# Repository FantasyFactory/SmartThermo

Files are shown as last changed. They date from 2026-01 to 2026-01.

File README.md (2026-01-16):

# SmartThermo
Smart advanced IR thermometer con ESP32-C3 e MicroPython

## Descrizione
Termometro a infrarossi "smart" basato su ESP32-C3 con display OLED SSD1306 e sensore MLX90614. Il progetto include un'interfaccia di configurazione navigabile tramite pulsanti e supporto per funzionalità avanzate come controllo WiFi, termostato PID e integrazione Tapo.

## Hardware

### Componenti
- **ESP32-C3**: microcontrollore con MicroPython
- **Display OLED SSD1306**: 128x64 pixel, interfaccia I2C
- **Sensore MLX90614**: termometro a infrarossi, interfaccia I2C
- **5 Pulsanti**: navigazione menu (UP, DOWN, LEFT, RIGHT, FIRE)
- **Laser**: puntatore per misurazione
- **Buzzer**: feedback audio

### Pinout
```
PIN_SDA    = 5   # I2C Data
PIN_SCL    = 6   # I2C Clock
PIN_LEFT   = 3   # Pulsante sinistra
PIN_RIGHT  = 4   # Pulsante destra
PIN_FIRE   = 0   # Pulsante fuoco/conferma
PIN_LASER  = 9   # Controllo laser
PIN_UP     = 10  # Pulsante su
PIN_DOWN   = 7   # Pulsante giù
PIN_BUZZER = 1   # Buzzer
```

### Connessioni I2C
- Frequenza I2C: 100kHz (limitata dal sensore MLX90614)
- Display OLED: indirizzo 0x3C
- Sensore MLX90614: indirizzo 0x5A (default)

## Struttura Software

Il progetto è organizzato in modo modulare per ottimizzare l'uso della memoria di MicroPython:

```
src/
├── boot.py              # Script di avvio automatico
├── main.py              # Entry point principale
├── config.py            # Gestione configurazione (singleton)
├── config.json          # File di configurazione
├── menu.py              # Sistema di menu generico
├── setup.py             # App di configurazione
├── app.py               # App principale termometro
├── wifi_manager.py      # Gestione WiFi (STA/AP/BOTH)
├── web_server.py        # Web server HTTP con API REST
├── drivers/
│   ├── ssd1306.py       # Driver display OLED
│   └── mlx90614.py      # Driver sensore temperatura IR
└── static/
    ├── index.html       # Interfaccia web
    ├── style.css        # Stili interfaccia
    └── app.js           # JavaScript interfaccia
```

### Architettura

#### 1. Config (`config.py`)
Classe singleton per gestire la configurazione:
- Lettura/scrittura file JSON
- Accesso tramite properties (es. `config.PIN_UP`, `config.wifi_mode`)
- Metodi `get(path)` e `set(path, value)` per accesso gerarchico
- Metodo `reload()` per ricaricare dopo modifiche

#### 2. Menu (`menu.py`)
Sistema di menu navigabile generico che supporta:
- **Label**: separatori/etichette
- **Level**: menu con sottovoci
- **Action**: esegue un callback
- **Int**: valori interi con min/max/step
- **Float**: valori decimali con min/max/step
- **IP**: indirizzi IPv4 (4 ottetti 0-255)
- **List**: selezione da lista di stringhe
- **Bool**: ON/OFF

Navigazione:
- **UP/DOWN**: scorrono le voci (o modificano valori in editing)
- **RIGHT**: entra in sottomenu/editing o esegue azione
- **LEFT**: esce da sottomenu/editing

#### 3. Setup (`setup.py`)
App di configurazione che mappa i valori di `config.json` su un menu navigabile:
- WiFi: Mode, SSID selection
- Preferences: Laser, BigNum, Reading mode, Refresh rate
- Thermostat: Active, Target, PID parameters, Auto-tune
- Tapo: Enable, IP
- Save and Exit / Exit (without save)

#### 4. Main (`main.py`)
Entry point che:
- Inizializza hardware (I2C, display, sensori)
- Controlla se entrare in setup mode (pulsante FIRE premuto all'avvio)
- Gestisce il passaggio tra app con cleanup memoria
- Avvia l'app principale

## Configurazione

Il file `config.json` contiene tutte le impostazioni:

```json
{
  "pins": { ... },
  "wifi": {
    "mode": "AP|STA|BOTH|Off",
    "known": [{"ssid": "...", "password": "..."}],
    "selected": 0,
    "ap_credentials": {...}
  },
  "preferences": {
    "laser": true|false,
    "bignum": true|false,
    "reading": "OnShoot|Continue",
    "refresh": 500
  },
  "thermostat": {
    "active": true|false,
    "target": 50,
    "p": 1.0,
    "i": 0.0,
    "d": 0.0
  },
  "tapo": {
    "enabled": true|false,
    "ip": "192.168.x.x"
  }
}
```

## Installazione

1. Installa MicroPython sull'ESP32-C3
2. Copia tutti i file dalla cartella `src/` sulla memoria del dispositivo
3. Riavvia il dispositivo

### Upload tramite ampy
```bash
ampy --port /dev/ttyUSB0 put src/boot.py
ampy --port /dev/ttyUSB0 put src/main.py
ampy --port /dev/ttyUSB0 put src/config.py
ampy --port /dev/ttyUSB0 put src/config.json
ampy --port /dev/ttyUSB0 put src/menu.py
ampy --port /dev/ttyUSB0 put src/setup.py
ampy --port /dev/ttyUSB0 mkdir drivers
ampy --port /dev/ttyUSB0 put src/drivers/ssd1306.py drivers/ssd1306.py
```

### Upload tramite Thonny
1. Apri Thonny IDE
2. Connetti all'ESP32-C3
3. Copia tutti i file mantenendo la struttura

## Uso

### Avvio Normale
All'accensione, il dispositivo avvia l'app principale del termometro.

### Modalità Setup
1. Tieni premuto il pulsante **FIRE** durante l'accensione
2. Naviga il menu con i pulsanti direzionali
3. Modifica le impostazioni
4. Seleziona "Save and Exit" per salvare

### Navigazione Menu Setup
- **UP/DOWN**: scorrono le voci del menu
- **RIGHT**: entra in un sottomenu o attiva editing
- **LEFT**: esce dal sottomenu o dall'editing
- In editing:
  - **UP/DOWN**: modificano il valore
  - **LEFT/RIGHT**: per IP, cambiano l'ottetto da modificare

## Gestione Memoria

Il progetto implementa strategie per ottimizzare la memoria limitata di MicroPython:
- Separazione tra app setup e principale
- Cleanup con `del` e `gc.collect()` dopo ogni modulo
- Singleton per la classe Config
- Ricarica configurazione da JSON invece di mantenerla in memoria

## App Principale

L'app principale (`app.py`) implementa tutte le funzionalità del termometro:

### Funzionalità

#### Lettura Temperature
- **Sensore MLX90614**: lettura temperatura oggetto e ambiente via I2C
- **Modalità OnShoot**: legge temperatura quando si preme il pulsante FIRE
- **Modalità Continue**: lettura continua con refresh configurabile (50-1000ms)
- **Feedback**: beep opzionale alla lettura e controllo laser

#### Display
- **Modalità normale**: mostra entrambe le temperature e target termostato
- **Modalità BigNum**: visualizza solo temperatura oggetto in grande
- **Refresh rate configurabile**: da 50ms a 1000ms

#### Connettività WiFi
- **Modalità Off**: nessuna connessione
- **Modalità STA**: client, connessione a rete WiFi esistente
- **Modalità AP**: access point per configurazione
- **Modalità BOTH**: client + access point simultanei
- **Fallback automatico**: se STA fallisce, passa ad AP

#### Web Server & API REST

Il web server è accessibile all'indirizzo IP del dispositivo (porta 80) e fornisce:

**API Temperature:**
- `GET /api/temp` - Lettura temperatura oggetto
- `GET /api/ambient` - Lettura temperatura ambiente

**API Termostato:**
- `GET /api/target` - Ottiene target e stato termostato
- `POST /api/target` - Imposta target e attiva/disattiva

**API Configurazione:**
- `GET /api/config` - Ottiene configurazione completa
- `POST /api/config` - Aggiorna configurazione

**API WiFi:**
- `GET /api/wifi/scan` - Scansiona reti disponibili
- `POST /api/wifi/test` - Testa connessione a rete
- `POST /api/wifi/save` - Salva configurazione WiFi

**API Status:**
- `GET /api/status` - Status completo del sistema

#### Interfaccia Web

Interfaccia web responsive accessibile via browser:
- **Dashboard temperature**: visualizzazione real-time con auto-refresh
- **Controllo termostato**: attiva/disattiva e imposta target
- **Configurazione WiFi**: scan reti, test connessione, salvataggio
- **Editor configurazione**: modifica diretta del JSON
- **System status**: info WiFi, IP, SSID connesso

### Termostato (Base)

Funzionalità termostato di base implementata:
- Attivazione/disattivazione via config o web
- Impostazione target temperature
- Visualizzazione target su display
- TODO: Implementazione controllo PID completo
- TODO: Integrazione Tapo per controllo remoto

## TODO

Funzionalità da completare:
- **Controllo PID**: implementazione algoritmo PID per termostato
- **Auto-tune PID**: procedura automatica di calibrazione parametri
- **Integrazione Tapo**: controllo smart plug Tapo per attuazione termostato
- **Logging**: salvataggio storico temperature su file
- **Grafici**: visualizzazione trend temperature su interfaccia web

## Licenza
MIT License

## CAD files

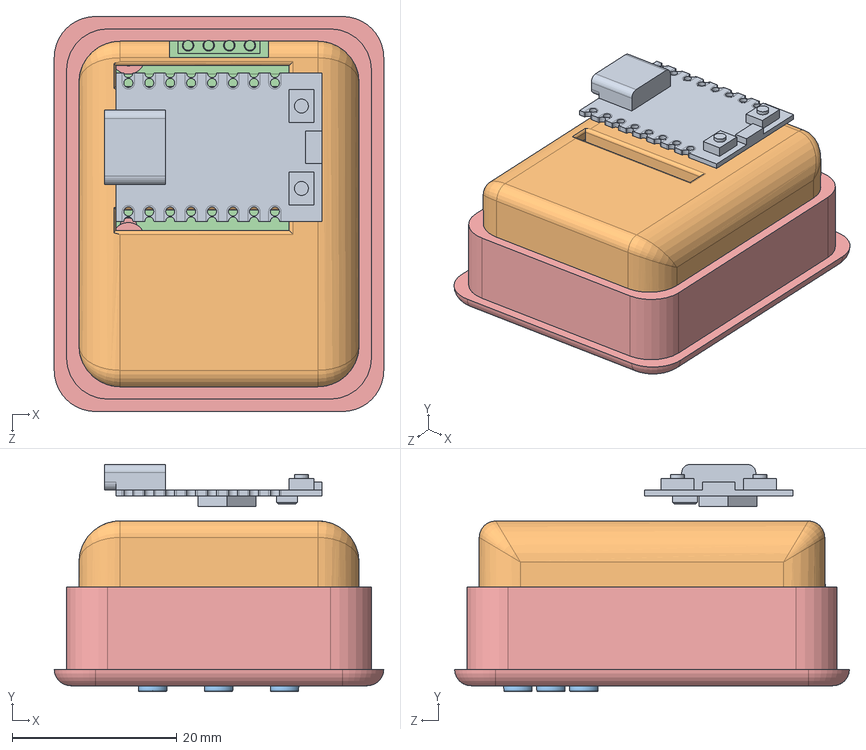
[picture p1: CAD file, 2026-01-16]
cad/AssiemetappoSLDASM.SLDASM
40.0 x 27.6 x 47.9 mm
tappo
oled
pulsante x 4
tappotappo
ESP32-C3 SuperMini

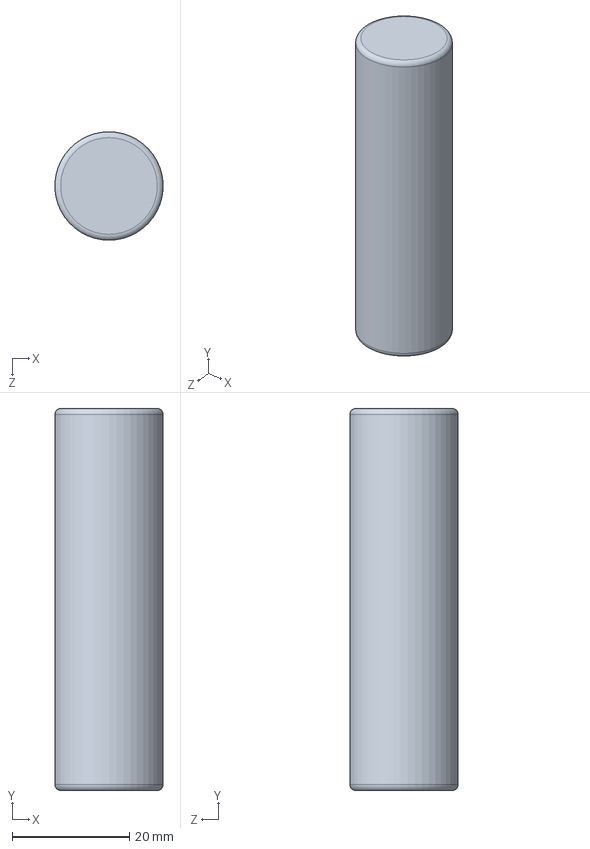
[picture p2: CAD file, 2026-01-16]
cad/Cell.SLDPRT
18.5 x 65.2 x 18.5 mm

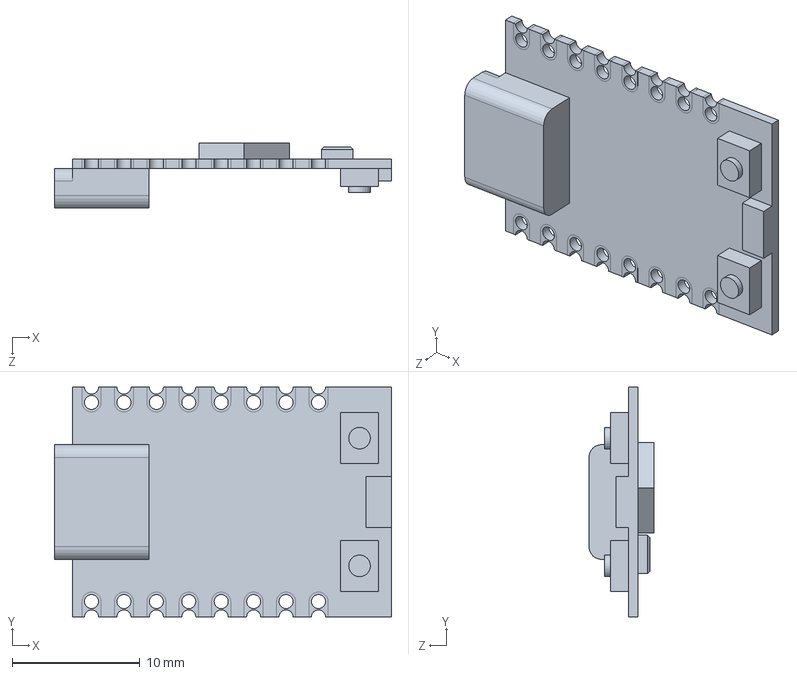
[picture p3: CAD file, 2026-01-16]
cad/ESP32-C3 SuperMini.SLDPRT
26.4 x 18.0 x 5.10 mm

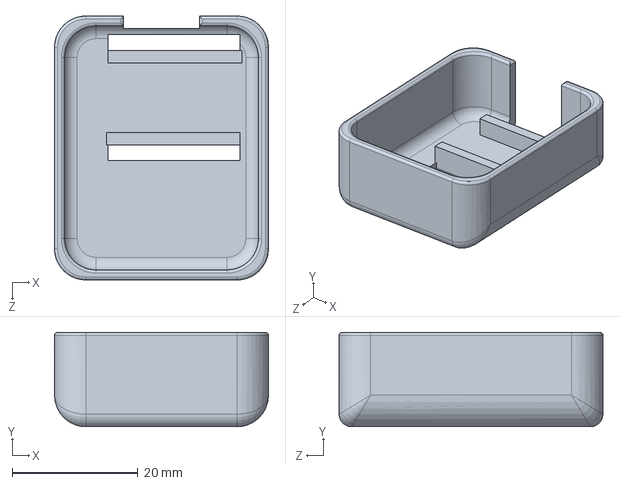
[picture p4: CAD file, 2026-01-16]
cad/tappotappo.SLDPRT
34.0 x 15.0 x 41.9 mm

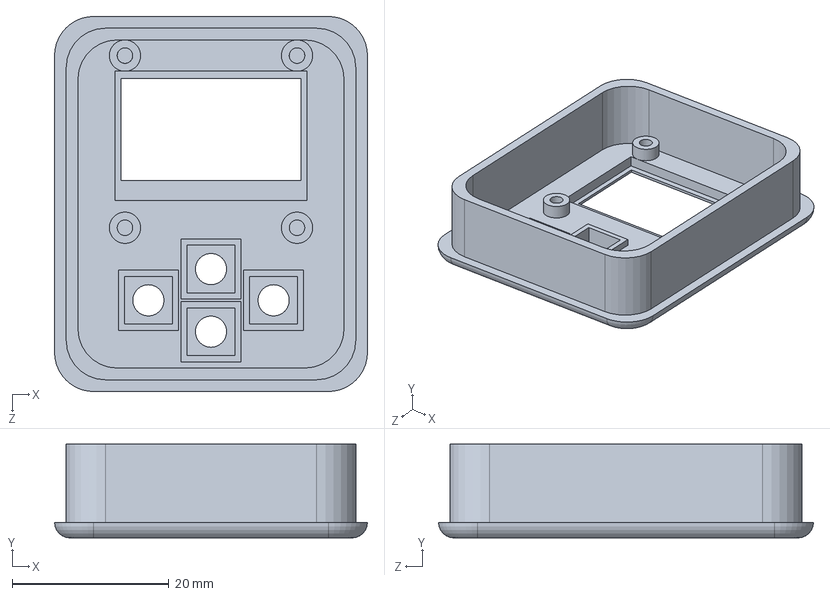
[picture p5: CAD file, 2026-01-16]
cad/tappo.SLDPRT
40.0 x 12.0 x 47.9 mm

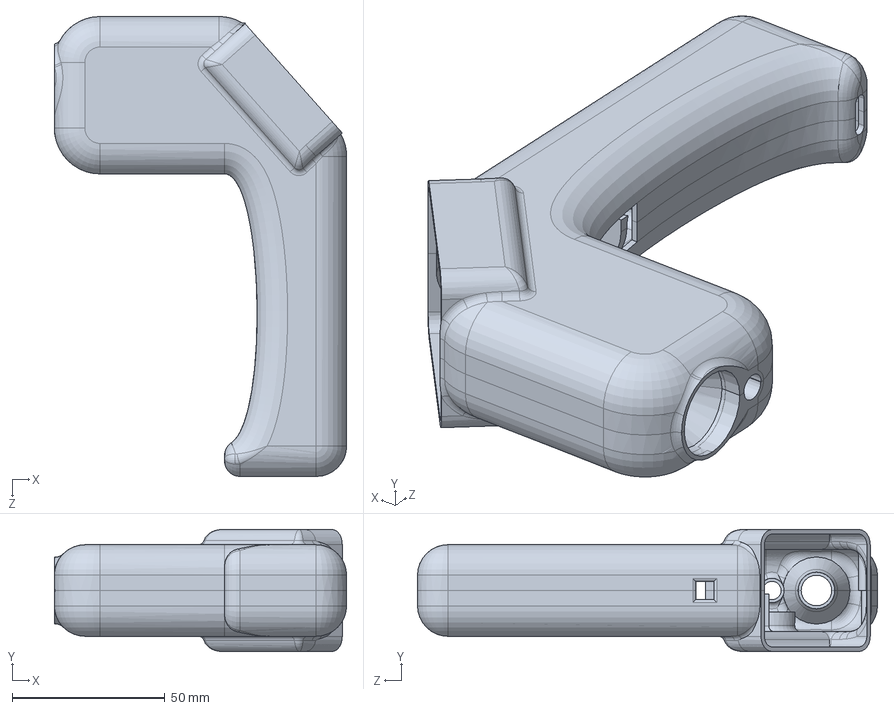
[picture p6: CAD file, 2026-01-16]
cad/pistola.SLDPRT
95.8 x 40.0 x 150.7 mm

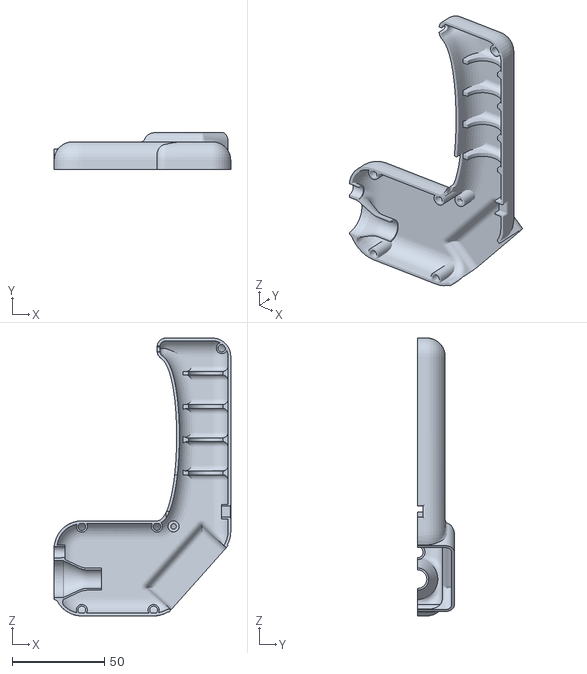
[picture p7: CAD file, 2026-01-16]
cad/pistola2.STL
95.8 x 20.0 x 150.7

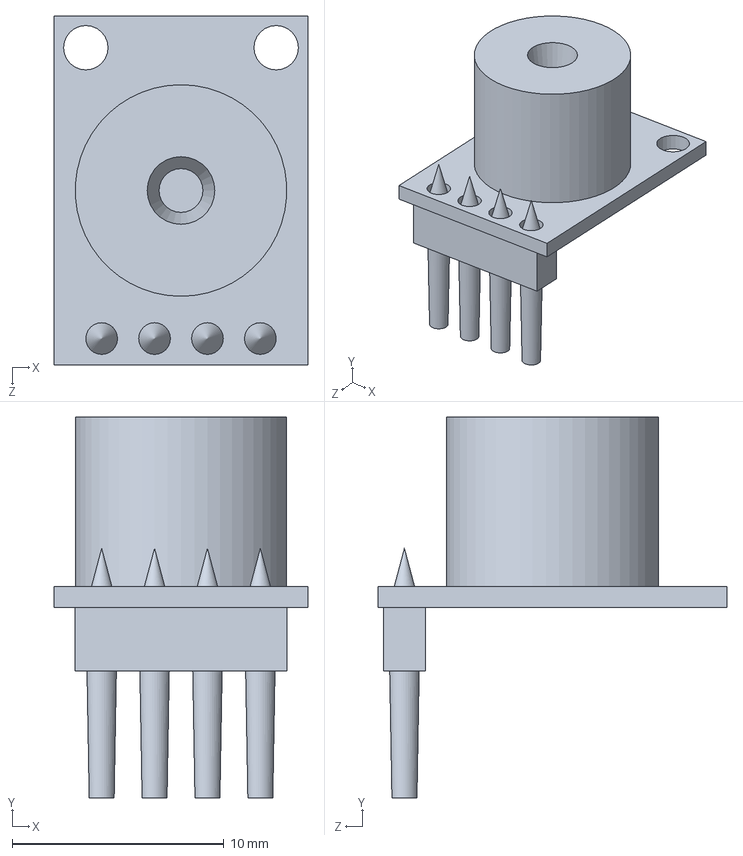
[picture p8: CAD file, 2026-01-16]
cad/gy-906.SLDPRT
12.0 x 18.0 x 16.5 mm

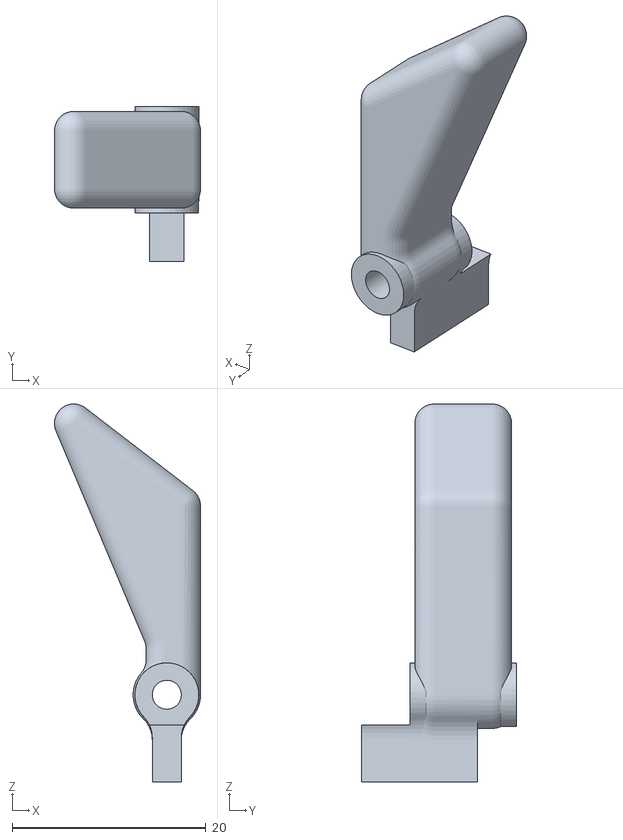
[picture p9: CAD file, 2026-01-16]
cad/Trigger2.STL
15.1 x 16.0 x 39.0

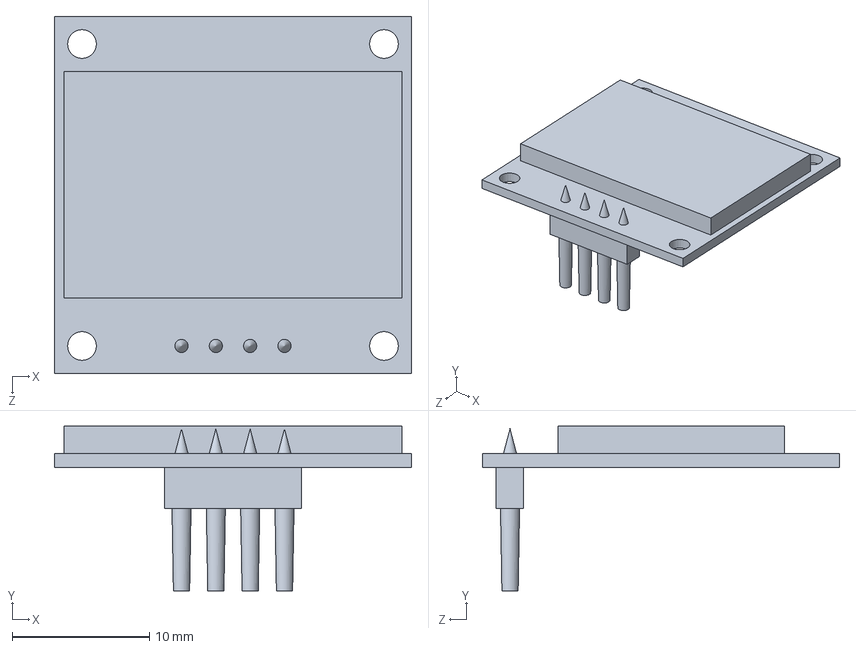
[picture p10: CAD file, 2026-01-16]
cad/oled.SLDPRT
26.0 x 12.0 x 26.0 mm

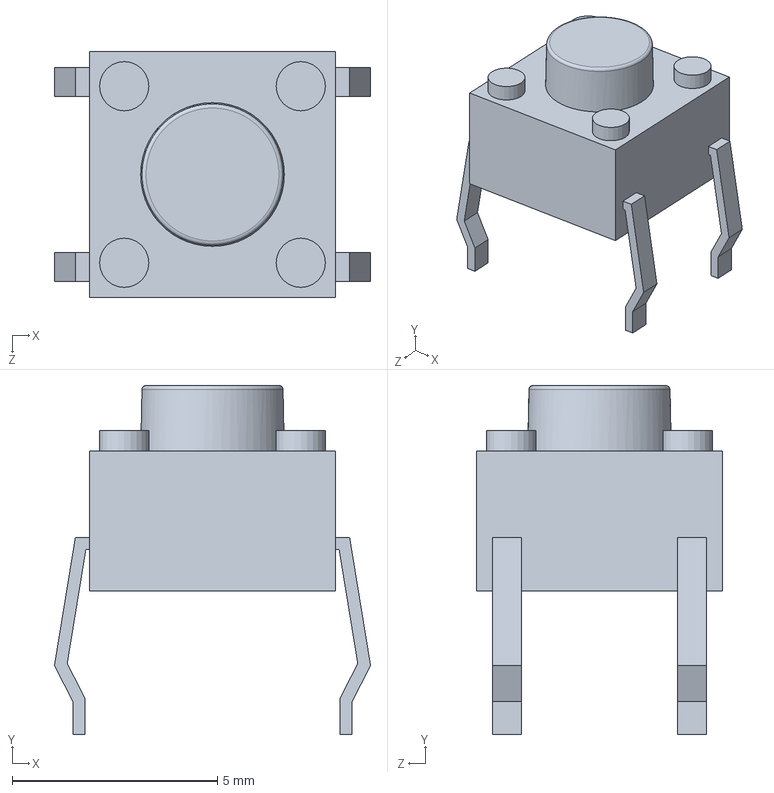
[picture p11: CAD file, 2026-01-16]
cad/pulsante.SLDPRT
7.70 x 8.50 x 6.00 mm

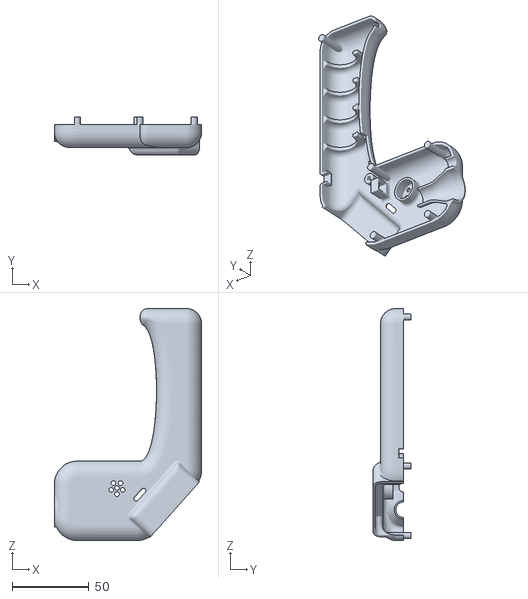
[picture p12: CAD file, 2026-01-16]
cad/pistola1.STL
95.8 x 25.0 x 150.7

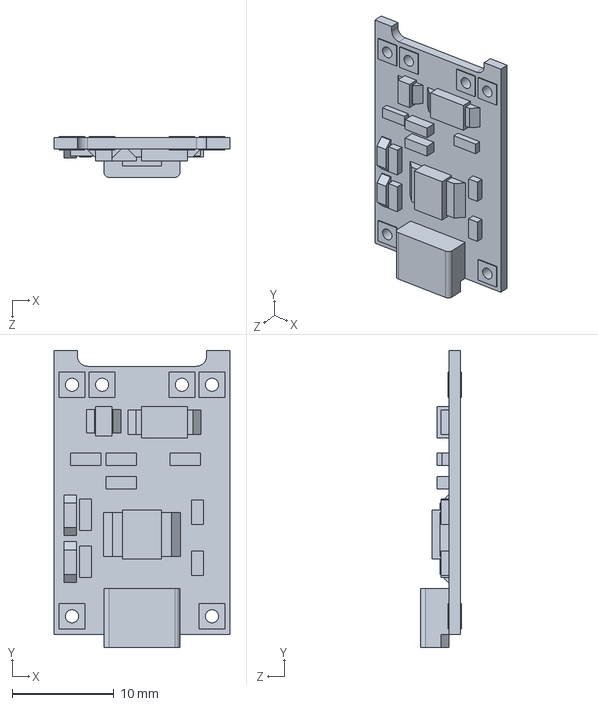
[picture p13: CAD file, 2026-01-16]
cad/tp4056 micro usb 18650 charger.SLDPRT
17.3 x 29.2 x 4.00 mm

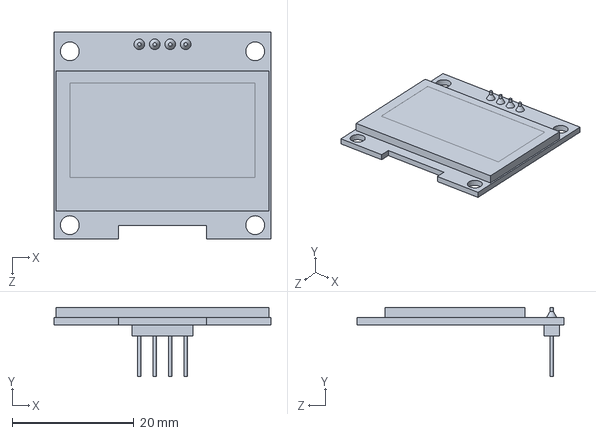
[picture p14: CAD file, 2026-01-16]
cad/Display_OLED_SSD1306_1.3inch.SLDPRT
35.7 x 11.4 x 34.0 mm

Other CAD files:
cad/laser.SLDPRT
cad/Trigger.SLDPRT
cad/Trigger.STL
cad/pistola.STL
cad/tappo.STL
cad/tappotappo.STL

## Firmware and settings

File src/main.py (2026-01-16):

"""
SmartThermo - Main Entry Point
Termometro a infrarossi smart con ESP32-C3, OLED e sensore MLX90614
"""
import gc
import sys
from machine import Pin, I2C
import time

# Importa driver e configurazione
from drivers.ssd1306 import SSD1306_I2C
from config import Config


class SmartThermo:
    """Classe principale per gestire il dispositivo"""

    def __init__(self):
        """Inizializza l'hardware"""
        print("SmartThermo starting...")

        # Carica configurazione
        self.config = Config()

        # Inizializza I2C
        self.i2c = I2C(
            0,
            scl=Pin(self.config.PIN_SCL),
            sda=Pin(self.config.PIN_SDA),
            freq=100000  # Limitato a 100kHz per MLX90614
        )
        print("I2C initialized")

        # Scansiona I2C per vedere i dispositivi connessi
        devices = self.i2c.scan()
        print(f"I2C devices found: {[hex(d) for d in devices]}")

        # Inizializza pulsanti per controllo avvio PRIMA di tutto
        # RIGHT per entrare in setup all'avvio
        # FIRE per bloccare l'avvio (debug mode)
        print("Initializing buttons...")
        self.btn_right = Pin(self.config.PIN_RIGHT, Pin.IN, Pin.PULL_UP)
        self.btn_fire = Pin(self.config.PIN_FIRE, Pin.IN, Pin.PULL_UP)

        # Breve delay per stabilizzare i pin
        time.sleep(0.05)

        # Verifica subito se FIRE è premuto
        if self.btn_fire.value() == 0:
            print("\n" + "="*40)
            print("!!! DEBUG MODE DETECTED !!!")
            print("FIRE button is pressed")
            print("="*40 + "\n")

        # Inizializza display OLED
        try:
            self.display = SSD1306_I2C(128, 64, self.i2c)
            print("Display initialized")
        except Exception as e:
            print(f"Error initializing display: {e}")
            self.display = None

        # Mostra splash screen (dà 1 secondo per premere FIRE)
        if self.display:
            self.show_splash()

    def show_splash(self):
        """Mostra schermata di avvio"""
        self.display.fill(0)
        self.display.text("SmartThermo", 20, 10, 1)
        self.display.text("v1.0", 50, 25, 1)
        self.display.text("Hold FIRE", 28, 45, 1)
        self.display.text("for Debug", 28, 55, 1)
        self.display.show()

        # Sleep più lungo per dare tempo di premere FIRE
        # Durante questo tempo controlliamo continuamente
        start = time.ticks_ms()
        while time.ticks_diff(time.ticks_ms(), start) < 1500:  # 1.5 secondi
            if self.btn_fire.value() == 0:
                print("DEBUG: FIRE pressed during splash!")
            time.sleep(0.1)

    def check_setup_mode(self):
        """Controlla se entrare in modalità setup (pulsante RIGHT premuto all'avvio)"""
        return self.btn_right.value() == 0

    def check_debug_mode(self):
        """Controlla se entrare in debug mode (pulsante FIRE premuto all'avvio)"""
        return self.btn_fire.value() == 0

    def run_setup(self):
        """Avvia l'app di setup"""
        print("Starting setup mode...")

        # Importa e avvia setup
        import setup
        setup.main(self.display, self.i2c)

        # Cleanup del modulo setup per liberare memoria
        del sys.modules['setup']
        del setup
        gc.collect()

        print("Setup mode exited")

        # Ricarica la configurazione (potrebbe essere stata modificata)
        self.config.reload()

    def run_main_app(self):
        """Avvia l'app principale del termometro"""
        # Se FIRE premuto all'avvio, entra in DEBUG MODE (non avvia l'app)
        if self.check_debug_mode():
            print("\n" + "="*40)
            print("DEBUG MODE - App NOT started")
            print("FIRE button pressed at boot")
            print("REPL is now available")
            print("="*40 + "\n")

            if self.display:
                self.display.fill(0)
                self.display.text("DEBUG MODE", 25, 20, 1)
                self.display.text("REPL Ready", 25, 35, 1)
                self.display.show()

            # Non avviare l'app - semplicemente ritorna al REPL
            # Thonny può ora connettersi senza causare reset
            return

        # Altrimenti avvia app normale
        print("Starting main app...")

        # Importa e avvia app principale
        import app
        app.main(self.display, self.i2c)

        # Cleanup del modulo app per liberare memoria
        del sys.modules['app']
        del app
        gc.collect()

        print("Main app exited")

    def run(self):
        """Loop principale"""
        # Controlla se entrare in setup
        if self.check_setup_mode():
            self.run_setup()

        # Avvia app principale
        self.run_main_app()


def main():
    """Entry point"""
    try:
        app = SmartThermo()
        app.run()
    except KeyboardInterrupt:
        print("\nShutdown by user")
    except Exception as e:
        print(f"Fatal error: {e}")
        import sys
        sys.print_exception(e)
    finally:
        gc.collect()
        print("SmartThermo stopped")


if __name__ == '__main__':
    main()

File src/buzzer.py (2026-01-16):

from machine import Pin, PWM
import time

def beep(pin_num, frequency, duration_ms):
    """
    Genera un beep usando PWM
    
    Args:
        pin_num: Numero GPIO del pin collegato al buzzer
        frequency: Frequenza del tono in Hz (1-1000 per ESP8266)
        duration_ms: Durata del beep in millisecondi
    """
    try:
        # Crea oggetto PWM
        buzzer = PWM(Pin(pin_num))
        
        # Imposta frequenza
        buzzer.freq(frequency)
        
        # Imposta duty cycle al 50% (512 su 1023) per volume massimo
        buzzer.duty(512)
        
        # Aspetta per la durata specificata
        time.sleep_ms(duration_ms)
        
        # Ferma il PWM
        buzzer.duty(0)
        buzzer.deinit()
        
    except Exception as e:
        print(f"Errore beep: {e}")

# Versione con controllo volume
def beep_volume(pin_num, frequency, duration_ms, volume=50):
    """
    Genera un beep con controllo volume
    
    Args:
        pin_num: Numero GPIO del pin
        frequency: Frequenza in Hz (1-1000)
        duration_ms: Durata in ms
        volume: Volume in percentuale (0-100)
    """
    try:
        buzzer = PWM(Pin(pin_num))
        buzzer.freq(frequency)
        
        # Converti volume percentuale in duty cycle (0-1023)
        duty = int((volume / 100) * 1023)
        buzzer.duty(duty)
        
        time.sleep_ms(duration_ms)
        
        buzzer.duty(0)
        buzzer.deinit()
        
    except Exception as e:
        print(f"Errore beep: {e}")
        

# Classe Buzzer per uso più avanzato
class Buzzer:
    def __init__(self, pin_num):
        self.pin_num = pin_num
        self.pwm = None
    
    def beep(self, frequency=1000, duration_ms=100, volume=50):
        """Singolo beep"""
        beep_volume(self.pin_num, frequency, duration_ms, volume)
    
    def double_beep(self, frequency=1000, duration_ms=100, pause_ms=100):
        """Doppio beep"""
        self.beep(frequency, duration_ms)
        time.sleep_ms(pause_ms)
        self.beep(frequency, duration_ms)
    
    def success(self):
        """Suono di successo (tono ascendente)"""
        self.beep(800, 100)
        self.beep(1000, 100)
        self.beep(1200, 150)
    
    def error(self):
        """Suono di errore (tono discendente)"""
        self.beep(1200, 100)
        self.beep(1000, 100)
        self.beep(800, 200)
    
    def alert(self, times=3):
        """Allarme ripetuto"""
        for _ in range(times):
            self.beep(1500, 200)
            time.sleep_ms(100)
    
    def click(self):
        """Suono click per feedback pulsanti"""
        self.beep(2000, 20, volume=30)
    
    def melody(self, notes):
        """
        Suona una melodia
        notes: lista di tuple (frequenza, durata_ms)
        """
        for freq, duration in notes:
            if freq == 0:  # Pausa
                time.sleep_ms(duration)
            else:
                self.beep(freq, duration)
            time.sleep_ms(10)  # Piccola pausa tra note
            
    def note_on(self, frequency, volume=50):
        try:
            self.pwm = PWM(Pin(self.pin_num))
            self.pwm.freq(frequency)
            
            # Converti volume percentuale in duty cycle (0-1023)
            duty = int((volume / 100) * 1023)
            self.pwm.duty(duty)
            
        except Exception as e:
            print(f"Errore beep: {e}")
        
    def note_off(self):
        try:
            self.pwm.duty(0)
            self.pwm.deinit()
            
        except Exception as e:
            print(f"Errore beep: {e}")

# Esempi di utilizzo
if __name__ == "__main__":
    # Esempio semplice
    BUZZER_PIN = 1  # GPIO15 per ESP8266
    
    # Beep singolo
    beep(BUZZER_PIN, 1000, 200)
    
    # Con controllo volume
    beep_volume(BUZZER_PIN, 800, 300, volume=75)
    
    # Usando la classe
    buzzer = Buzzer(BUZZER_PIN)
    
    # Feedback per menu
    buzzer.click()  # Click su pulsante
    time.sleep(1)
    
    buzzer.success()  # Operazione completata
    time.sleep(1)
    
    buzzer.error()  # Errore
    time.sleep(1)
    
    # Melodia semplice (note Do-Re-Mi)
    melody_notes = [
        (262, 200),  # Do
        (294, 200),  # Re
        (330, 200),  # Mi
        (262, 400),  # Do lungo
    ]
    buzzer.melody(melody_notes)

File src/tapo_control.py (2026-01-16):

"""
Controllo Tapo P100 Smart Plug
Implementazione semplificata per MicroPython
"""
import urequests
import json
import hashlib
import time


class TapoP100:
    """Controller per Tapo P100 smart plug"""

    def __init__(self, ip, email, password):
        """
        Inizializza il controller Tapo

        Args:
            ip: indirizzo IP del dispositivo
            email: email account Tapo
            password: password account Tapo
        """
        self.ip = ip
        self.email = email
        self.password = password
        self.token = None
        self.cookie = None
        self._state = None

    def _encode_credentials(self):
        """Encode credenziali per autenticazione"""
        # Hash password
        pwd_hash = hashlib.sha1(self.password.encode()).digest()
        # Encode email
        email_hash = hashlib.sha1(self.email.encode()).digest()
        return email_hash, pwd_hash

    def turn_on(self):
        """Accende il dispositivo"""
        try:
            url = f"http://{self.ip}/app"
            payload = {
                "method": "set_device_info",
                "params": {
                    "device_on": True
                }
            }

            # Richiesta semplificata - potrebbe richiedere autenticazione
            response = urequests.post(url, json=payload, timeout=5)
            result = response.json()
            response.close()

            self._state = True
            return result.get('error_code', -1) == 0

        except Exception as e:
            print(f"Error turning on Tapo: {e}")
            return False

    def turn_off(self):
        """Spegne il dispositivo"""
        try:
            url = f"http://{self.ip}/app"
            payload = {
                "method": "set_device_info",
                "params": {
                    "device_on": False
                }
            }

            response = urequests.post(url, json=payload, timeout=5)
            result = response.json()
            response.close()

            self._state = False
            return result.get('error_code', -1) == 0

        except Exception as e:
            print(f"Error turning off Tapo: {e}")
            return False

    def get_state(self):
        """
        Ottiene lo stato corrente del dispositivo

        Returns:
            True se acceso, False se spento, None se errore
        """
        try:
            url = f"http://{self.ip}/app"
            payload = {
                "method": "get_device_info"
            }

            response = urequests.post(url, json=payload, timeout=5)
            result = response.json()
            response.close()

            if result.get('error_code', -1) == 0:
                self._state = result.get('result', {}).get('device_on', None)
                return self._state

            return None

        except Exception as e:
            print(f"Error getting Tapo state: {e}")
            return self._state  # Ritorna ultimo stato conosciuto

    @property
    def is_on(self):
        """Ritorna True se il dispositivo è acceso"""
        return self._state if self._state is not None else False

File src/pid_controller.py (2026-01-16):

"""
Controllore PID per termostato
Implementazione semplice di un controllore PID
"""
import time


class PIDController:
    """Controllore PID con anti-windup"""

    def __init__(self, kp, ki, kd, setpoint=0):
        """
        Inizializza il PID

        Args:
            kp: guadagno proporzionale
            ki: guadagno integrale
            kd: guadagno derivativo
            setpoint: valore target
        """
        self.kp = kp
        self.ki = ki
        self.kd = kd
        self.setpoint = setpoint

        self._last_error = 0
        self._integral = 0
        self._last_time = time.ticks_ms()

    def update(self, current_value):
        """
        Calcola l'output del PID

        Args:
            current_value: valore corrente

        Returns:
            Output del PID (0-100%)
        """
        now = time.ticks_ms()
        dt = time.ticks_diff(now, self._last_time) / 1000.0  # in secondi

        if dt <= 0:
            dt = 0.001

        # Calcola errore
        error = self.setpoint - current_value

        # Proporzionale
        p_term = self.kp * error

        # Integrale (con anti-windup)
        self._integral += error * dt
        # Limita integrale per evitare windup
        self._integral = max(min(self._integral, 100), -100)
        i_term = self.ki * self._integral

        # Derivativo
        d_term = 0
        if dt > 0:
            d_term = self.kd * (error - self._last_error) / dt

        # Output totale
        output = p_term + i_term + d_term

        # Limita output 0-100%
        output = max(min(output, 100), 0)

        # Salva stato
        self._last_error = error
        self._last_time = now

        return output

    def set_tunings(self, kp, ki, kd):
        """Aggiorna i parametri PID"""
        self.kp = kp
        self.ki = ki
        self.kd = kd

    def set_setpoint(self, setpoint):
        """Aggiorna il setpoint"""
        self.setpoint = setpoint

    def reset(self):
        """Reset del controllore"""
        self._integral = 0
        self._last_error = 0
        self._last_time = time.ticks_ms()

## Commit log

2025-12-30 Implementa app setup per SmartThermo con sistema menu navigabile
    - Aggiunge classe Config (singleton) per gestione configurazione JSON
    - Implementa sistema Menu generico con supporto per Label, Level, Action, Int, Float, IP, List, Bool
    - Crea app Setup con mappatura completa delle impostazioni (WiFi, Preferences, Thermostat, Tapo)
    - Aggiunge driver SSD1306 per display OLED I2C
    - Implementa main.py con gestione hardware e passaggio tra app
    - Ottimizza gestione memoria per MicroPython
    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
2025-12-30 Implementa app principale SmartThermo con WiFi, Web Server e API REST
    - Aggiunge driver MLX90614 per lettura temperature oggetto e ambiente
    - Implementa WiFi Manager con modalità STA/AP/BOTH e fallback automatico
    - Crea Web Server HTTP asincrono con API REST complete
    - Implementa interfaccia web responsive con controllo real-time
    - Aggiunge app principale con display temperature e controllo laser
    - Supporta modalità lettura OnShoot e Continue configurabili
    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
2025-12-30 Fix: invia risposte HTTP in chunk per file grandi
    Risolve problema di troncamento file JavaScript.
    - Usa loop send() con chunk di 1KB invece di singolo send()
    - Previene troncamento su file >2KB in MicroPython
    - Garantisce invio completo di app.js (12KB)
    [web_server.py]
2025-12-30 Fix: refactor invio file statici con headers/body separati
    Risolve definitivamente troncamento file grandi.
    - Separa headers e body invece di concatenare tutto
    - Invia in chunk da 512 byte con gc.collect() tra chunk
    - Evita allocazione memoria eccessiva su MicroPython
    - Garantisce invio completo di file >10KB
    [web_server.py]
2025-12-30 Fix: calcola Content-Length in byte UTF-8, non caratteri
    RISOLVE definitivamente il troncamento!
    - len(string) conta caratteri (emoji = 1 carattere)
    - len(string.encode('utf-8')) conta byte reali (emoji = 3-4 byte)
    - Questo causava Content-Length: 11922 invece di 11997
    - Browser troncava a 11922 byte come da header errato
    - Aggiunto charset=utf-8 in Content-Type per chiarezza
    [web_server.py]
2025-12-30 Implementa app completa con 3 modalità operative e controllo Tapo
    App principale completamente riscritta con:
    Display Layout:
    - Header: WiFi status (STA/AP/Off) + SSID connesso
    - Area centrale (44px): contenuto modalità
    - Footer: menu navigabile "[Mode] Set>"
    3 Modalità Operative:
    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
2025-12-30 Implementa ingresso setup da app e auto-tune PID conservativo
    Ingresso Setup:
    - Pulsante RIGHT dal footer "Set>" entra in setup
    - Passa callback autotune all'app setup
    - Mantiene WiFi e web server attivi
    - Ricarica config e parametri PID al ritorno
    Auto-tune PID Conservativo (CRITICAL):
    - Algoritmo 4 fasi per NON superare MAI il target
    - Fase 1: Misura inerzia termica
    * Riscalda a 70% target, spegni, misura overshoot
    * Misura tempo di overshoot peak
    - Fase 2: Misura cooling rate
    * Aspetta discesa di 10C
    * Calcola velocità di raffreddamento
    - Fase 3: Calcola parametri PID conservativi
    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
    [app.py]
2025-12-30 Add DEBUG MODE per fermare boot con pulsante FIRE
    Modifiche:
    - RIGHT all'avvio: entra in setup (era FIRE)
    - FIRE all'avvio: entra in DEBUG MODE
    * Blocca esecuzione in loop infinito
    * Display mostra 'DEBUG MODE - REPL Ready'
    * Console mostra messaggio chiaro
    * Permette interazione con REPL in Thonny
    - Risolve problema impossibilità di fermare app in sviluppo
    Uso:
    - Reset + tieni premuto FIRE = debug mode
    - Reset + tieni premuto RIGHT = setup mode
    - Reset normale = app principale
    [main.py]
2025-12-30 Fix BigNum: passa float invece di stringa a printNum()
    [app.py]
2025-12-30 Fix DEBUG MODE: init pulsanti prima di display e controllo durante splash
    [main.py]
2025-12-30 Fix DEBUG MODE: usa return invece di loop infinito per compatibilità Thonny
    [main.py]
2026-01-13 minor fix
    [Assieme1.SLDASM, AssiemetappoSLDASM.SLDASM, CFFFP_pistola1.3mf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]
2026-01-13 Add backup files and remove obsolete CAD files
    [Assieme1.SLDASM, CFFFP_pistola1.3mf]
2026-01-14 Add linear calibration for MLX90614 sensor with two-point calibration
2026-01-14 Fix buzzer crash in Continue mode: check for None and use beep() instead of note_on()
    [app.py]
2026-01-14 Revert to original buzzer behavior with note_on() but add None check
    [app.py]
2026-01-14 Add debug logging for temperature calibration troubleshooting
2026-01-15 Add raw temperature display: expose calibrated, raw and ambient temps in web UI
2026-01-15 Add interactive calibration menu with GUI editor for sensor calibration points
2026-01-15 Add calibration enable/disable toggle: use raw temp when disabled, calibrated when enabled
2026-01-15 Add emissivity management: EEPROM read/write, material presets, menu configuration
    - MLX90614 driver: add CRC-8, read_emissivity(), write_emissivity()
    - Config: add emissivity section with material presets (KNSB, Ceramica, Metalli, etc.)
    - Setup menu: Material Type selection, Read/Write EEPROM with confirmation
    - Presets: Pelle Umana (0.98), KNSB/Polimeri (0.90), Metalli (0.20-0.70)
    - Warning: EEPROM has ~100k write cycles limit
2026-01-15 Fix setup menu and adapt for 128px display
    Fixes:
    - Add missing min/max/step params for emissivity Custom value (TYPE_FLOAT)
    - Add error handling in menu render to prevent 'closure' object crashes
    - Add try-catch in _handle_up and _handle_down for robustness
    UI improvements for 128px display:
    - Abbreviate menu labels: "Preferences" -> "Prefs", "Emissivity" -> "Emissiv",
    "Calibration" -> "Calibr", "Auto tune PID" -> "Tune PID"
    - Abbreviate material names: "Pelle Umana" -> "Skin", "Plastica Nera" -> "Plastic",
    "KNSB/Polimeri" -> "KNSB", "Ceramica Opaca" -> "Ceramic",
    "Metalli Opachi" -> "M.Matt", "Metalli Lucidi" -> "M.Shiny"
    - Shorten "Continue" -> "Cont" in reading mode
    - Change "Save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
    [config.py, menu.py]
2026-01-15 Fix menu action errors and add quick material switching
    - Add try-catch in menu.py when executing actions to prevent 'closure' errors
    - Display error message on screen when action fails instead of crashing
    - Now shows "Action Error!" with action name and error details
    Features:
    - Add quick material (emissivity) switching with LEFT button in main app
    - LEFT button cycles through all material presets (Skin, Plastic, KNSB, etc.)
    - Shows material name and emissivity value briefly on screen
    - Beep confirmation on material change
    - Material persisted to config (not auto-saved until "Save & Exit" in setup)
    Button behavior:
    - LEFT in Thermostat mode: enters target editing (unchanged)
    - LEFT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
    [app.py, menu.py]
